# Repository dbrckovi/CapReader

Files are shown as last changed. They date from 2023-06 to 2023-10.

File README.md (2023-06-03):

# CapReader
Arduino Nano based capacitance meter

# Brief description:
Can measure capacitors from 1nF upwards.

When button is pressed, continuously discharges and charges the capacitor through different resistors, measuring time it takes for a capacitor to charge up to 63.2%.
When the value is measured, discharges the capacitor and value is displayed on LCD.

Button must be held until measurement is finished.

# Problems:
 
 - Measuring capacitors of about 10uF takes longer than 100+F. Resistor values must be calibrated to avoid these jumps in measurement time
 - Measurements which took < 10ms are discarded. This value is probably too high.

# Ideas:
 - Try using micros instead of millis
 - Try replacing 10M resistor with 100M to see if pF capacitances can be measured.
 - Try adding 220 Ohm resistor to see if really big capacitors can be measured in reasonable time.

# Todo:
 - Add code comments
 - Add schematic
 - Write proper readme
 - Choose proper license

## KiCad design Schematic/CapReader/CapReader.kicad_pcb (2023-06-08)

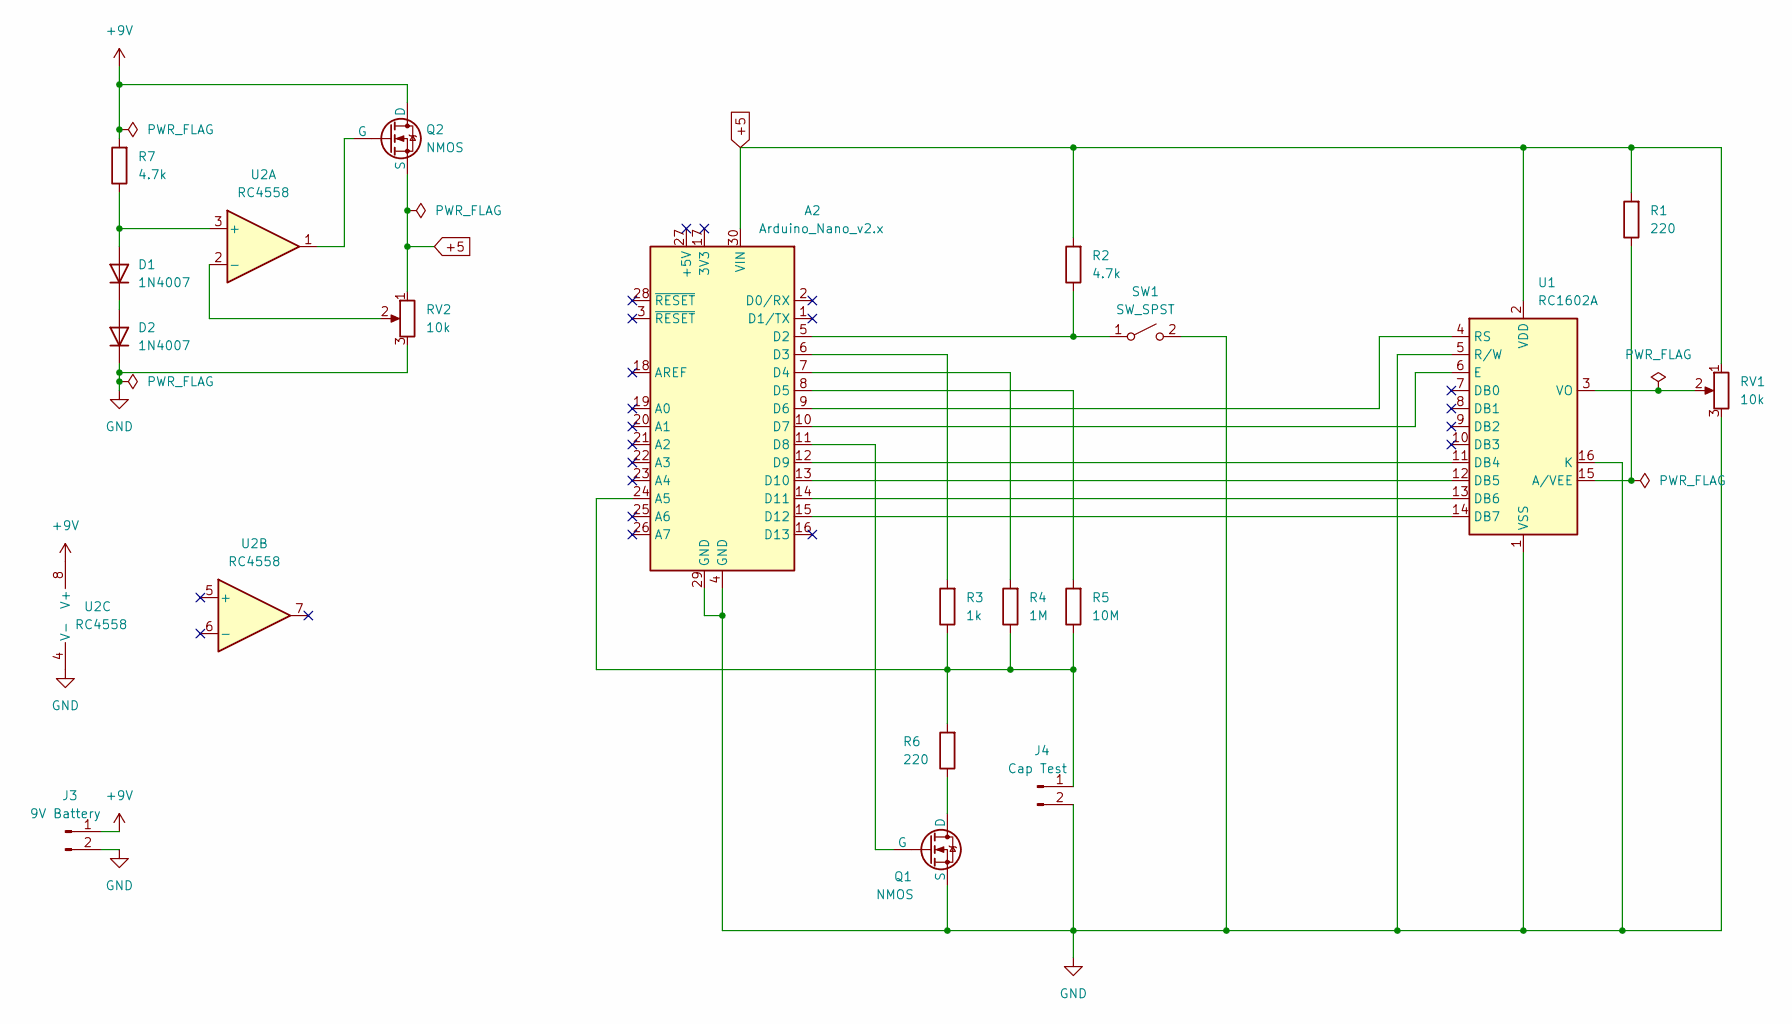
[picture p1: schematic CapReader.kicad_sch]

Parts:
A2: Arduino_Nano_v2.x; Arduino_Nano
D1, D2: 1N4007; D_DO-41_SOD81_P10.16mm_Horizontal
J3: 9V Battery; TestPoint_2Pads_Pitch2.54mm_Drill0.8mm
J4: Cap Test; TestPoint_2Pads_Pitch2.54mm_Drill0.8mm
Q1, Q2: NMOS; TO-220-3_Vertical
R1, R6: 220; R_Axial_DIN0309_L9.0mm_D3.2mm_P12.70mm_Horizontal
R2, R7: 4.7k; R_Axial_DIN0309_L9.0mm_D3.2mm_P12.70mm_Horizontal
R3: 1k; R_Axial_DIN0309_L9.0mm_D3.2mm_P12.70mm_Horizontal
R4: 1M; R_Axial_DIN0309_L9.0mm_D3.2mm_P12.70mm_Horizontal
R5: 10M; R_Axial_DIN0309_L9.0mm_D3.2mm_P12.70mm_Horizontal
RV1, RV2: 10k; Potentiometer_Bourns_3386F_Vertical
SW1: SW_SPST; JWT_A3963_1x02_P3.96mm_Vertical
U1: RC1602A
U2: RC4558; DIP-8_W7.62mm_Socket

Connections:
+5: A2.30 (VIN), Q2.3 (S), R1.2, R2.2, RV1.1, RV2.1, U1.2 (VDD)
+9V: J3.1, Q2.1 (D), R7.2, U2.8 (V+)
GND: A2.4 (GND), A2.29 (GND), D2.1 (K), J3.2, J4.2, Q1.3 (S), RV1.3, RV2.3, SW1.2 (B), U1.1 (VSS), U1.5 (R/W), U1.16 (K), U2.4 (V-)
unnamed: A2.24 (A5), J4.1, R3.1, R4.1, R5.1, R6.2
unnamed: A2.5 (D2), R2.1, SW1.1 (A)
unnamed: A2.6 (D3), R3.2
unnamed: A2.7 (D4), R4.2
unnamed: A2.8 (D5), R5.2
unnamed: A2.9 (D6), U1.4 (RS)
unnamed: A2.10 (D7), U1.6 (E)
unnamed: A2.11 (D8), Q1.2 (G)
unnamed: A2.12 (D9), U1.11 (DB4)
unnamed: A2.13 (D10), U1.12 (DB5)
unnamed: A2.14 (D11), U1.13 (DB6)
unnamed: A2.15 (D12), U1.14 (DB7)
unnamed: D1.2 (A), R7.1, U2.3 (+)
unnamed: D1.1 (K), D2.2 (A)
unnamed: Q1.1 (D), R6.1
unnamed: Q2.2 (G), U2.1
unnamed: R1.1, U1.15 (A/VEE)
unnamed: RV1.2, U1.3 (VO)
unnamed: RV2.2, U2.2 (-)

Board: 2 copper layers, 19 parts (0 on the bottom side), 22 nets, no tracks yet.

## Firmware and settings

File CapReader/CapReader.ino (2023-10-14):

#include <LiquidCrystal.h>

const float R1 = 1000.0;
const float R2 = 1000000.0;
const float R3 = 10000000.0;

const int CHARGE_VALUE = 647;     // (647 is 63.2% of 1023)
const int MAX_INITIAL_VOLTAGE = 3;
const int BUTTON = 2;
const int CHARGE1 = 5;  //1k
const int CHARGE2 = 4;  //1M
const int CHARGE3 = 3;  //10M
const int DISCHARGE = 6;
const int rs = 7, en = 8, d4 = 9, d5 = 10, d6 = 11, d7 = 12;
LiquidCrystal lcd(rs, en, d4, d5, d6, d7);

void setup() {
  pinMode(BUTTON, INPUT);
  pinMode(CHARGE1, INPUT);
  pinMode(CHARGE2, INPUT);
  pinMode(CHARGE3, INPUT);
  pinMode(DISCHARGE, OUTPUT);

  digitalWrite(DISCHARGE, LOW);
  lcd.begin(16, 2);
  PrintLine(0, "Ready");
}

void loop() 
{
  if(digitalRead(BUTTON) == LOW) 
  {
    Measure();
    PrintLine(0, "Ready");
  }
}

void Measure()
{
  PrintLine(0, "Measuring...");
  PrintLine(1, " ");

  unsigned long elapsed = 0;
  float R;

  Discharge();
  R = R1;
  elapsed = ChargeAndWait(CHARGE1);

  if (elapsed < 1000)
  {
    Discharge();
    R = R2;
    elapsed = ChargeAndWait(CHARGE2);
  }

  if (elapsed < 1000)
  {
    Discharge();
    R = R3;
    elapsed = ChargeAndWait(CHARGE3);
  }

  Discharge();

  if (elapsed > 1000) PrintLine(0, "Finished");
  else PrintLine(0, "Not sure");

  PrintCapacitance(elapsed, R);

  while(digitalRead(BUTTON) == LOW) {}
}

void Discharge()
{
  digitalWrite(DISCHARGE, HIGH);
  
  while(true)
  {
    if (analogRead(A5) <= MAX_INITIAL_VOLTAGE) break;
    if (digitalRead(BUTTON) == HIGH) break;
  }
  digitalWrite(DISCHARGE, LOW);
}

unsigned long ChargeAndWait(int pinNumber)
{
  pinMode(pinNumber, OUTPUT);
  digitalWrite(pinNumber, HIGH);
  unsigned long start_time = micros();
  unsigned long elapsed = 0;
  
  while (digitalRead(BUTTON) == LOW)
  {
    if (analogRead(A5) > CHARGE_VALUE) 
    {
      elapsed = micros() - start_time;
      break;
    }
  }
  digitalWrite(pinNumber, LOW);
  pinMode(pinNumber, INPUT);
  return elapsed;
}

void PrintVoltage(int voltage)
{
    String strVoltage = String(voltage);
    PrintLine(1, strVoltage);
}

void PrintCapacitance(unsigned long elapsedMillis, float R)
{
  double seconds = (double)elapsedMillis / 1000000.0;
  double fahrads = seconds / R;
  double milliFahrads = fahrads * 1000.0;
  double microFahrads = milliFahrads * 1000.0;
  double nanoFahrads = microFahrads * 1000.0;
  double picoFahrads = nanoFahrads * 1000.0;

  String out;
  
  if (fahrads > 1.0) out = String(fahrads) + " F";
  else if (milliFahrads > 1.0) out = String(milliFahrads) + " mF";
  else if (microFahrads > 1.0) out = String(microFahrads) + " uF";
  else if (nanoFahrads > 1.0) out = String(nanoFahrads) + " nF";
  else if (picoFahrads > 1.0) out = String(picoFahrads) + " pF";
  
  PrintLine(1, out);
}

void PrintLine(int line, String text)
{
    while (text.length() < 16)
    {
      text += ' ';
    }
  
    lcd.setCursor(0, line);
    lcd.print(text);
}

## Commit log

2023-06-08 Measuring micros instead of millis. Using CHARGE_VALUE value instead of hardcoded
2023-06-08 Added Kicad schematic
    [CapReader.kicad_pcb, CapReader.kicad_sch]
2023-10-14 Don't remember any more what was changed
    [CapReader.kicad_sch]
